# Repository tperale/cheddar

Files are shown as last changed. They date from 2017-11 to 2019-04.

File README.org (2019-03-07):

* Cheddar

*Cheddar* is a connected button based on the ESP8266.

** What is this ?

   Amazon created not a long time ago a connected button (called Dash
   button) that allows to make an order on Amazon just by pressing a
   single button facilitating the process of buying of household goods.
   It didn't take a long time before hackers started appropriating the
   object and use it for their own purposes:

   * [[https://medium.com/@brody_berson/hacking-amazon-s-5-dash-button-to-order-domino-s-pizza-9d19c9d04646][Hacking Amazon’s $5 Dash Button to order Domino’s Pizza]]
   * [[https://www.youtube.com/watch?v=qZpJ9W0wCks][How To Use the Amazon Dash with IFTTT and Home Assistant]]

   All that had to be done was to buy one, get the button ID through the
   Amazon app and encode that ID to _whatever_ was listening to the
   incoming query.  Amazon gave you a $5 connected piece of hardware,
   battery and case included that allowed you to do virtually anything
   with it.

   As amazing as this might sound, the problems of those buttons are:

   * You need an amazon premium account to purchase them and get the button ID.
   * You can't directly program them, which makes complex queries more
     difficult to run and embedding sensors impossible.
   * You need a server running somewhere locally to listen to the incoming queries.
   * You can't wake it up from external events other than by pressing the button.

** What to do ?

   Why not create our own open source "Amazon Dash button". It would
   also run on a battery, can be programmed and is
   Internet-connected. The ESP8266 microcontroller is used in a wide
   variety of projects and many frameworks are developed around + it's
   also really cheap !

   Powering an ESP8266 dev board (WEMOS D1, NodeMCU DevKit, Sparkfun
   ESP8266 Thing...) with a battery and waking it up when the button is
   pressed is quite a trivial problem and not fun. That's why I chose to
   create a PCB to host the ESP8266 module. Although it has some
   requirements:

   * Be able to program it and debug it from USB
   * Can run on batteries
   * Batteries should be rechargeable using the on board USB
   * It should be power efficient

   # TODO: add up to date schematic and .brd pictures

** BOM

*** Semiconductors

    | Ref | Qty | What                 | Value     | Footprint   |
    |-----+-----+----------------------+-----------+-------------|
    | Q1  |   1 | P-MOSFET             | DMG3415U  | SOT23-3     |
    | U1  |   1 | USB-Serial converter | CH340G    | SO-16-N     |
    | U2  |   1 | Battery charger      | MCP73831  | SOT23-5     |
    | U3  |   1 | uC + wireless module | ESP-12E   | ESP-12E_SMD |
    | U4  |   1 | Voltage regulator    | HT7333    | SOT89       |
    | D1  |   1 | Battery 100% LED     |           | 1206        |
    | D2  |   1 | Schottky diode       | 1PS79SB31 | SOD-523     |

*** Capacitors

    | Ref    | Qty | Value | Footprint |
    |--------+-----+-------+-----------|
    | C1, C9 |   2 | 220uF |      1206 |
    | C2, C3 |   2 | 22pF  |      1206 |
    | C4, C8 |   2 | 100nF |      1206 |
    | C5     |   1 | 10nF  |      1206 |
    | C6     |   1 | 22nF  |      1206 |
    | C7     |   1 | 1uF   |      1206 |

*** Resistors

    | Ref                | Qty | Value | Footprint |
    |--------------------+-----+-------+-----------|
    | R1                 |   1 | 470R  |      1206 |
    | R3, R5, R6, R7, R8 |   5 | 10kR  |      1206 |
    | R9                 |   1 | 100kR |      1206 |

*** Crystals

    | Ref | Qty | Value | Footprint                       |
    |-----+-----+-------+---------------------------------|
    | Y1  |   1 | 12Mhz | Crystal_SMD_3225-4pin_3.2x2.5mm |

*** Connectors

    | Ref    | Qty | Footprint                             |
    |--------+-----+---------------------------------------|
    | J1     |   1 | USB_Micro-B_Molex                     |
    | J2, J3 |   2 | Pin_Header_Straight_1x08_Pitch2.54mm  |
    | J4     |   1 | Pin_Header_Straight_1x02_Pitch2.54mm  |
    | J5     |   1 | JST_SH_SM02B-SRSS-TB_02x1.00mm_Angled |

*** Switch

    | Ref | Qty | Footprint         |
    |-----+-----+-------------------|
    | SW1 |   1 | SW_DIP_x1_W5.08mm |

*** References

    * [[https://www.youtube.com/watch?v=nbMfb0dIvYc&t=307s][Long lasting DIY "Amazon Dash Button" using an ESP8266]]
    * [[https://www.youtube.com/watch?v=6JD2RMDM88Y][Cheap IFTTT Button with spare ESP-01 finished]]
    * [[https://www.youtube.com/watch?v=wf_msvWv1jk][How to properly power the ESP8266 modules]]
    * [[https://github.com/espressif/esptool/wiki/ESP8266-Boot-Mode-Selection][ESP8266 Wiki - Boot Mode Selection]]
    * [[https://github.com/knewron-technologies/1btn][1btn]]
    * [[https://www.kickstarter.com/projects/805606890/gobutton-simple-wi-fi-connected-smart-button-for-e/description][goButton]]
    * [[https://github.com/DeqingSun/ESP8266-Dash-Button][ESP8266-Dash-Button]]

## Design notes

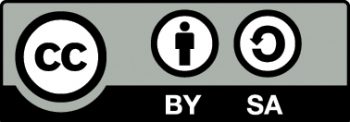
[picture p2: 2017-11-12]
pictures/license.jpg

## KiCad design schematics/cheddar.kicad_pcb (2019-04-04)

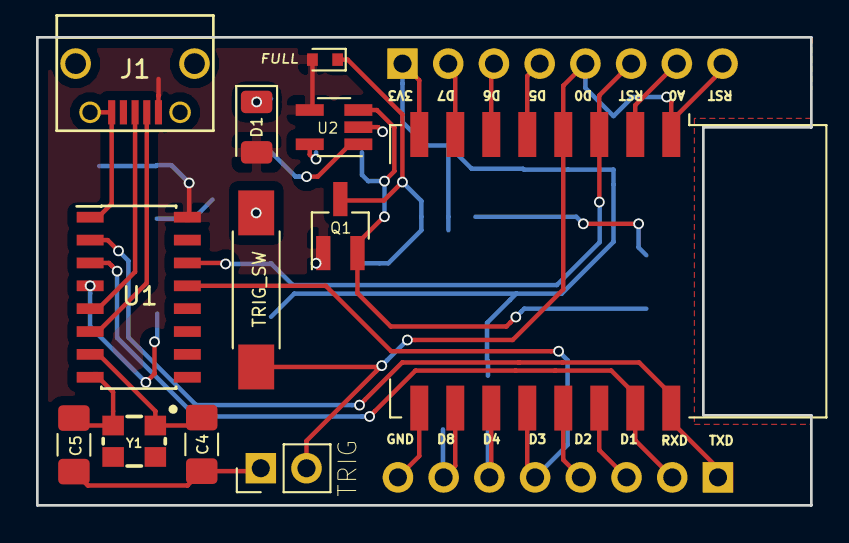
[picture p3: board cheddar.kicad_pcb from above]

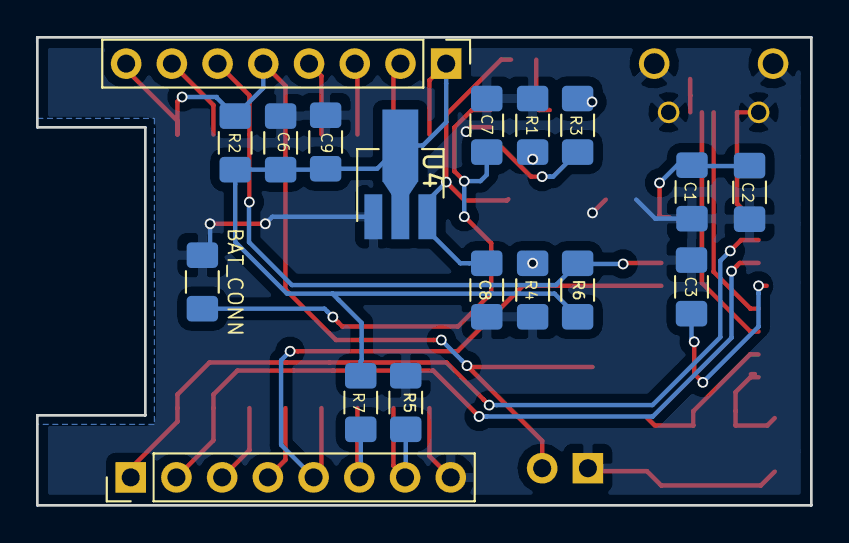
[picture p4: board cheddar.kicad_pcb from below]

Board: 2 copper layers, 43.0 x 26.0 mm, 26 parts (16 on the bottom side), 15 nets.

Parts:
BAT_CONN: BATT_CONN; R_1206_3216Metric_Pad1.42x1.75mm_HandSolder
C1, C6: 100nF; C_1206_3216Metric_Pad1.42x1.75mm_HandSolder
C2: 10nF; C_1206_3216Metric_Pad1.42x1.75mm_HandSolder
C3: 22nF; C_1206_3216Metric_Pad1.42x1.75mm_HandSolder
C4, C5: 22pF; C_1206_3216Metric_Pad1.42x1.75mm_HandSolder
C7: 1uF; C_1206_3216Metric_Pad1.42x1.75mm_HandSolder
C8, C9: 220uF; C_1206_3216Metric_Pad1.42x1.75mm_HandSolder
D1: GREEN; LED_1206_3216Metric
J1: USB_OTG; USB_Micro-B-custom
Q1: MOSFET_PCH; SOT-23_Handsoldering
R1, R2, R5, R6, R7: 10k; R_1206_3216Metric_Pad1.42x1.75mm_HandSolder
R3: 470; R_1206_3216Metric_Pad1.42x1.75mm_HandSolder
R4: 100k; R_1206_3216Metric_Pad1.42x1.75mm_HandSolder
TRIG: EXTERNAL_TRIGGER; PinHeader_1x02_P2.54mm_Vertical
TRIG_SW: SW_Push; SW_SPST_REED_CT05-XXXX-G1
U1: CH340G; SOIC-16_3.9x9.9mm_P1.27mm
U2: MCP73831; SOT-23-5_HandSoldering
U4: HT7333; SOT-89-3_Handsoldering
Y1: 12Mhz; CRYSTAL-SMD-3.2X2.5MM

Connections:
+3V3: C6.2, C9.1, R2.1, R6.2, R7.2, U4.2
+5V: C1.2, C2.2, D1.2, J1.1, Q1.1, R4.1, U1.16, U2.4
/CH_PD: R6.1, U1.14
/D+: J1.3, U1.5
/D-: J1.2, U1.6
/GPIO16: R2.2, TRIG.2, TRIG_SW.2
/XI: C4.1, U1.7, Y1.1
/XO: C5.1, U1.8, Y1.2
GND: BAT_CONN.1, C1.1, C2.1, C3.2, C4.2, C5.2, C6.1, C7.1, C8.2, C9.2, J1.5, J1.6, R1.2, R4.2, R5.2, TRIG.1, TRIG_SW.1, U1.1, U2.2, U4.1
unnamed: C3.1, U1.4
unnamed: BAT_CONN.2, C7.2, Q1.2, U2.3
unnamed: C8.1, Q1.3, U4.3
unnamed: D1.1, R3.2
unnamed: R1.1, U2.5
unnamed: R3.1, U2.1

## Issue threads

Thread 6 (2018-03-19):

Crystal footprint changed

tperale, 2018-03-19:
Not correct anymore it's too small for the smd crystal

Closed 2018-03-20.

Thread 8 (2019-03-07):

[kicad] reconnect wires in schematic

carlosgeos, 2019-03-07:
All the new kicad version 5 symbols are in place, but connections have changed and elements are disconnected.

Closed 2019-03-07.

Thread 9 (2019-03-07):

Test battery circuit

carlosgeos, 2019-03-07:
Test some single cell Li cell with MCP73831 + schottky + pchan mosfet circuit to see what it does.

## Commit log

2017-07-11 [add] Correction on boot mode pins
    [dash.sch]
2017-07-15 add libraries to project and link symbols with footprints
    [dash.kicad_pcb, dash.sch]
2017-08-03 [enh] Fix pin mode (output/input)
2017-08-03 [enh] Better power port placement with fixed pin mode for ICs
    [dash.sch]
2017-08-03 [fix] schematics gnd pins
2017-08-03 [enh] VSS connected directly to the battery
    [dash.sch]
2017-08-05 [add] Shitty design to start with
    [dash.kicad_pcb, dash.sch]
2017-08-07 [enh] Change crystal placement and size
    [dash.kicad_pcb]
2017-08-07 [add] TX/RX wiring to the ESP-12
    [dash.kicad_pcb]
2017-08-07 [fix] Correct wiring
    [dash.kicad_pcb]
2017-08-07 [fix] Last fixes
    [dash.kicad_pcb]
2017-08-07 [add] Signature because fun
    [dash.kicad_pcb]
2017-08-07 [fix] Fill the zone correctly
    [dash.kicad_pcb]
2017-08-08 [fix] upgrade components to match our needs
    [dash.kicad_pcb]
2017-09-17 [fix] Global dependencies to local dependencies (no more path problem)
    [dash.kicad_pcb, dash.sch]
2017-09-17 [enh] Remove useless solder pads to have more room for the components
    [dash.kicad_pcb]
2017-09-22 [fix] Relative path for the ESP-12 component
    [dash.sch]
2017-09-22 [fix] 3DShapes names
    [dash.kicad_pcb, dash.sch]
2017-09-23 [enh] Change capacitor value to match ceramic capacitor availability
    [dash.sch]
2017-09-24 [enh] Redesigned project to take less space
    [dash.kicad_pcb, dash.sch]
2017-09-24 [fix] unconnected
    [dash.kicad_pcb]
2017-09-24 [fix] Track near pad
    [dash.kicad_pcb]
2017-09-24 add copper cutout under antenna
    https://electronics.stackexchange.com/questions/294165/ground-pour-under-esp8266-12-e
    [dash.kicad_pcb]
2017-09-25 [enh] Reduce the PCB size
    [dash.kicad_pcb]
2017-09-25 [fix] various things
    [dash.kicad_pcb]
2017-09-27 [enh] No pcb under the antenna to ensure good signal
    [dash.kicad_pcb]
2017-09-27 [add] Pinout
    [dash.kicad_pcb, dash.sch]
2017-09-29 [enh] Add 3d models + better external trigger pad
    [dash.kicad_pcb, dash.sch]
2017-09-29 [fix] Right led footprint
    [dash.kicad_pcb]
2017-10-02 [fix] Change crystal footprint to match availability
    [dash.kicad_pcb, dash.sch]
2017-10-02 [add] Forgot to update sch
    [dash.sch]
2017-10-06 [enh] More infos on component + title block parameters
    [dash.sch]
2017-10-06 Add BOM to README
2017-10-20 [add] Link to cheap components
    [dash.sch]
2017-11-08 [rm] Indication on header pins
    [dash.kicad_pcb]
2017-11-08 [add] Link to ebay
    [dash.sch]
2017-11-08 [add] Link to buy switch on ebay
    [dash.sch]
2017-11-12 [chg] License to a hardware license
    [dash.sch]
2017-11-18 [enh] Changed pcb size
    [dash.kicad_pcb]
2017-11-23 [add] Dimensions to pcb layout
    [dash.kicad_pcb]
2017-11-23 [enh] Do not include gerbers
2017-12-09 [fix] Better re-read those datasheets, wrong HT7333 pad mapping on the pcb
    [dash.kicad_pcb, dash.sch]
2017-12-14 [fix] Change footprints to match component buyed
    [dash.kicad_pcb, dash.sch]
2018-02-08 load sharing (USB <-> battery), change to MCP73831
    add all lib dependencies locally
    restructure dirs
    less vias in pads !
    change top copper pour to 5V, not 3,3V
    type fottprint in readme
    [dash.kicad_pcb, dash.sch]
2018-02-09 finish routing
    [dash.kicad_pcb, dash.sch]
2018-02-09 swap USB connector for a THT one
    [dash.kicad_pcb, dash.sch]
2018-02-23 change USB connector to custom
    add URLAB logo
    [dash.kicad_pcb, dash.sch]
2018-02-23 modify schottky diode footprint to SOD523
    [dash.kicad_pcb, dash.sch]
2018-03-20 correct crystal footprint. fixes #6
    bigger button footprint
    EXTERNAL_TRIGGER is now through hole
    some re-routing
    [dash.kicad_pcb, dash.sch]
2019-03-06 symbol remaps (for KiCad version 5)
    [dash-2019-03-06-13-28-07.sch, dash-2019-03-06-13-33-40.sch]
2019-03-07 update README.md, more symbol remapping for KiCAD version 5
    [dash-2019-03-07-16-33-33.sch]
2019-03-07 cleanup project, rename dash->cheddar
    [cheddar.kicad_pcb, cheddar.sch, dash-2019-03-06-13-28-07.sch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]
2019-03-07 add symbols to schematic
    remove redundant symbol libs (KiCAD version 5 has them already)
    [cheddar.sch]
2019-03-07 fix #8, all components connected
    [cheddar.kicad_pcb, cheddar.sch]
2019-03-08 replace all footprints with standard lib ones
    remove unnecessary custom libs
    [cheddar.kicad_pcb, cheddar.sch]
2019-03-30 Reestructure board
    [cheddar.kicad_pcb]
2019-04-04 Routed new PCB
    [cheddar.kicad_pcb]
2019-04-04 Remove useless labeling
    [cheddar.kicad_pcb]
2019-04-04 [enh] better routing
    [cheddar.kicad_pcb]
